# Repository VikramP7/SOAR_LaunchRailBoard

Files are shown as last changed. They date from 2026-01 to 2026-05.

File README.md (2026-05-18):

*<div align="right"> Vikram Procter | Sept 13, 2025 </div>*

# SOAR - Launch Rail Board Specs

## Purpose Overview
- Use AFEs to convert analog sensor data to digital
- Sensors include load cells, thermocouples and anemometers
- Interface with Fill Systems Board (FSB) in Rocket Control Unit (RCU) to provide digital sensor data using UART over Serial RS485
- This board exists on the Launch Rail and is in IP rated box
- The board should also store sensor data to flash memory
- Replacing the Signal Observations Board (SOB) from Ouroboros

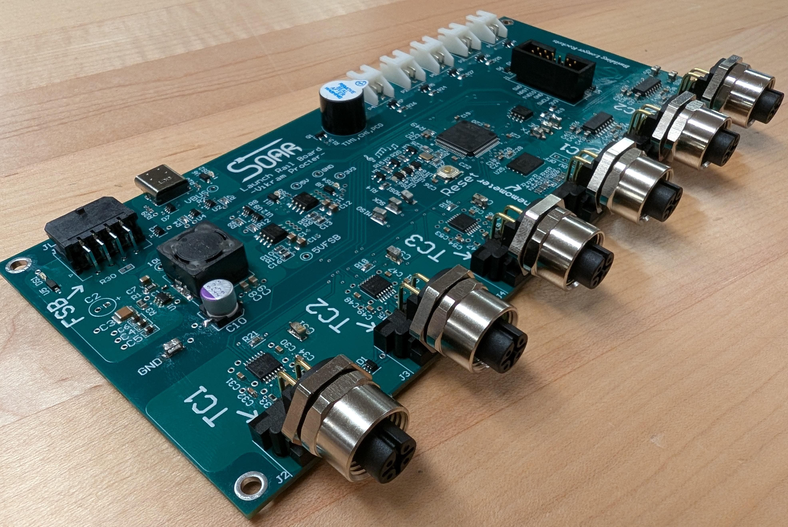
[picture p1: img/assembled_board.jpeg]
Image of Assembled Board


## TODO for V2
- Only use 0603 (remove that stupid 0402 R8)
- Fix same part mismatches (eg. CGA3E2X7R1E104K080AA 0.1uF 0603 and 06035C104KAT2A 100nF 0603)

## Design Review
- [Review Google Doc](https://docs.google.com/document/d/1Cs_T_aiDTq1XPzXbdogT7vXFGTcwQEdisFsmFb62IeU/edit?usp=sharing)

## FSB Connection
### Data Transfer
-   Run simplexed UART over RS-485 twisted pairs
-   Using [Digital to RS485 serial converter](https://www.digikey.ca/en/products/detail/texas-instruments/SN65HVD72D/3283549)

### Power Supply
-   FSB provides 48V

### Connector Choice
-   Board to Wire Molex header [0430450800](https://www.digikey.ca/en/products/detail/molex/0430450800/252529)
-   Board to side panel edge cable assembly [2147561082](https://www.molex.com/en-us/products/part-detail/2147561082), [digikey](https://www.digikey.ca/en/products/detail/molex/2147561082/12180697?s=N4IgTCBcDa4IwBYDsBWAbHADADggXQF8g)
Molex FSB Wiring Standard

-   These are pin numbers based on schematic  

-   Maybe panel Edge connector: M12, 8 position circular connector [54-00184](https://www.digikey.ca/en/products/detail/tensility-international-corp/54-00184/13548494)
-   panel exterior cable 5m Cable [M12A08MR-12AMR-SD005](https://www.digikey.ca/en/products/detail/amphenol-ltw/M12A08MR-12AMR-SD005/21315761)

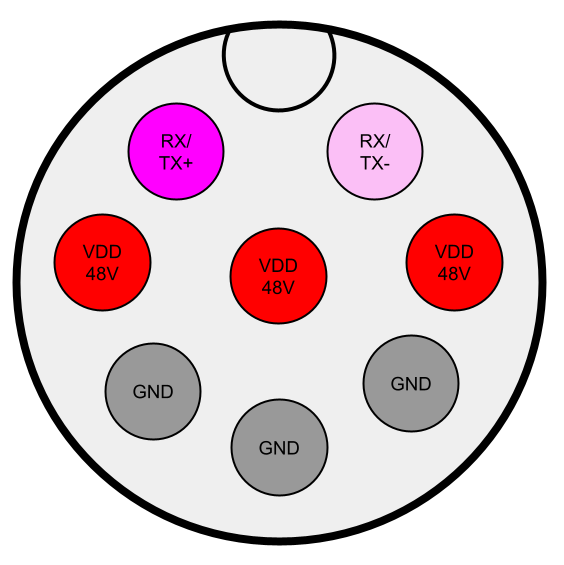
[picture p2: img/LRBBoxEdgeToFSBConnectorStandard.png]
Box Edge LRB to FSB Connector Standard


### RS485 to Digital IC
-   Two [SN65HVD72D](https://www.digikey.ca/en/products/detail/texas-instruments/SN65HVD72D/3283549) ICs will be used to allow for full duplex
-   Each will be used for only Rx or Tx
-   The Tx SN65HVD72D has the DE and RE bar pins held high for driver enable
-   The Rx SN65HVD72D has the DE and RE bar pins held high for receiver enable
-   The connector wires for RS485 will not be connected to ESD protection devices as the SN65HVD72D has built in esd protection

## Power Regulation
-   48V input power stepped down to 10V using Buck converter
-   Power indicator LEDs use [AL5809-20S1-7](https://www.digikey.ca/en/products/detail/diodes-incorporated/AL5809-20S1-7/5030204) for current limiting
### Buck Converter [LMR51625XDDCR](https://www.digikey.ca/en/products/detail/texas-instruments/LMR51625XDDCR/25991371)
- Configuration provided by [Webench SVG](https://webench.ti.com/power-designer/switching-regulator/select) and Ultium Design
- Vout=10V, f=400kHz, Voutpk=18mV, Iout=2A 
- For 10V: $\frac{R_{FBT}}{R_{FBB}}=\frac{V_{out}-0.8}{0.8}=11.5$,
- $R_{FBT}=100k\Omega$ $R_{FBB}=8.66k\Omega$
Buck LMR51625XDDCR Schematic
### LDO Regulator [MIC5209YM](https://www.digikey.ca/en/products/detail/microchip-technology/MIC5209YM/771747)
- For output voltage $V_{out}=1.242V\times(1+\frac{R2}{R1})$ where $R2<470k\Omega$
- For 5V: $\frac{R2}{R1}=3.0257=\frac{453\Omega}{150\Omega}=\frac{47.5k}{15.8k}$
- For 3V3: $\frac{R2}{R1}=1.657=\frac{750\Omega}{453\Omega}=\frac{75k\Omega}{45.3k\Omega}$
- Two caps on output is for ultra low noise, one is optional along with 470pF
### Power Supply Priority
- Allow switching between 5V from USB, programming header, and FSB power, this prioritizes FSB power and ignore usb if usb is plugged in while FSB is providing power. But allow USB to power when FSB is not providing power. The programming header supply has lowest priority and will only be used if no other power sources are connected. 
- ORing of sources is achieved using [LM66100DCKR](https://www.digikey.ca/en/products/detail/texas-instruments/LM66100DCKR/10273183) chip
- This chip also does reverse polarity protection
- Each nCE has a very weak pull down to ensure that the CE is not just floating when other power supplies are not connected.
- This weak pull down does mean that when all power supplies are connected 5V is connected to ground through the 220k. Also if all power supplies are connected 5V are occasionally connected to eachother through a 10k.

*<div align="center">**Power selection truth table:**</div>*
| FSB 5V | USB 5V | PRGM 5V | FSB_nCE | USB_nCE | PRGM_nCE |
|:---:|:---:|:---:|:---:|:---:|:---:|
| 0|0|0  | 0w|0w|0w|
| 0|0|1  | 0 | 1|0w|
| 0|1|0  | 1 |0st|1|
| 0|1|1  | 1 |0st|1|
| 1|0|0  | 0 |1|1fsb|
| 1|0|1  | 0 |1|1fsb|
| 1|1|0  | 0 |1|1fsb|
| 1|1|1  | 0 |1|1fsb|

## Programming Header
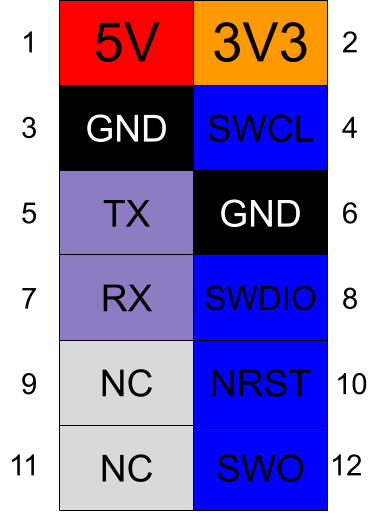
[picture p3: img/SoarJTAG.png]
JTAG
Use 12 pin keyed 2.54mm molex connector [0702461201](https://www.digikey.ca/en/products/detail/molex/0702461201/760167) for Serial Wire Debug Programming protocol 
-   Should be compatible with connector bellow or just free wires
-   Keyed Connector [0022552122](https://www.digikey.ca/en/products/detail/molex/0022552122/313630?s=N4IgTCBcDa5grPMBGMEC6BfIA) and crimps [0016020069](https://www.digikey.ca/en/products/detail/molex/0016020069/1656191?s=N4IgTCBcDaIIwDYAMYlIQThAXQL5A) 24-30 AWG wire gauge
-   Include reset button
-   3V3 is purposefully not connected to 3V3 on board.
-   The STLink connector side uses [0901420010](https://www.digikey.ca/en/products/detail/molex/0901420010/760752) with crimps [0016020069](https://www.digikey.ca/en/products/detail/molex/0016020069/1656191?s=N4IgTCBcDaIIwDYAMYlIQThAXQL5A) (same as the board side so should work)

## Sensors
### What Sensors:
- 1x [Anemometer](): Analog input, connected to MCU ADC.
    - [Adafruit](https://www.adafruit.com/product/1733?srsltid=AfmBOor_Ywvu-j-peoAsiU7YbtJCmZtmGhgEJ9A_gKxrkaFAT5jR3P_o): $44.95 three wire interface (pwr, gnd, signal)
    - [AliExpress](https://www.aliexpress.com/item/1005009826264755.html): $14.08 RS-485 differential pair, I think
    - [Amazon](https://www.amazon.ca/Environment-Anemometer-Greenhouses-Environmental-Stations-ect/dp/B0867KJBCZ/): $46.89 Very similar to ali express, or 4 wire interface. 
- 3x [Thermocouples](): Using [AFE](https://www.digikey.ca/en/products/detail/analog-devices-inc-maxim-integrated/MAX31856MUD/5050138) with SPI output 
- 2x [Load Cells](): Using [AFE](https://www.digikey.ca/en/products/detail/nuvoton-technology-corporation/NAU7802SGI/2769782) with I<sup>2</sup>C output

### Sensor Connectors:
-   M12 screw, 5 position circular board to wire connector [54-00247](https://www.tensility.com/products/54-00247), [digikey](https://www.digikey.ca/en/products/detail/tensility-international-corp/54-00247/13548445)
-   Wire assembly [50-00960](https://www.tensility.com/products/50-00960), [digikey](https://www.digikey.ca/en/products/detail/tensility-international-corp/50-00960/13548425)
LRB FSB connection standard
-   VDD (Pin 1): Provided to only the Load Cell (LC)
-   TC+/LC+ (Pin 2/4): Positive analog signal
-   AN- (Pin 5): Negative Analog signal
-   GND (Pin 3): Ground 

### Data Rate
-	Assume all sensor data is 16bit resolution each + bonus 32bit

## File System Over USB
-   USB C interface with STM to allow the LRB to show up as a mass storage device to offload data
-   If LRB can be powered over USB then that would be good for data offload to not require FSB
-   Using USB FS (no external phys required)
-   Using USB C and USB ab for compatibility, USB C will be conversion of old USB ab

## Flash Memory
-   Targeting 16 bit resolution and 1kHz sampling rate
-   `16bit * 4sensors + 32bonus bits = 96bit/sample `
-   `(96bit/sample)*(1000samples/s)*(1byte/8bits) = 12kB/s`
-   If data measuring is needed for 6 hours, total storage needs to be greater than **259.2MB**, **2073.6Mbit**
-   Using one [(*W25N04KVZEIR*)](https://www.digikey.ca/en/products/detail/winbond-electronics/W25N04KVZEIR/15182086) 4Gbit flash chip
-   Chip uses QuadSPI

## Buzzer
-   Using Same Sky [CMI-1210-5-95T](https://www.digikey.ca/en/products/detail/same-sky-formerly-cui-devices/CMI-1210-5-95T/15904111)
-   Connected to PWM PC0: TIM1, PWM Gen CH1 using NPN [MMBT3904-TP](https://www.digikey.ca/en/products/detail/micro-commercial-co/MMBT3904-TP/717395)

## Microcontroller Specs
### Data Sheet
-   [STM32G491ME
](https://www.st.com/resource/en/datasheet/stm32g491cc.pdf) data sheet

### System and Programming
-   BOOT0 pin is pulled down to GND through 10k, pad are there to change in future
-   Serial Wire Debug Programming protocol is used with NRST pin connected to reset button

### Power Supply
-   Supply voltage 1.71 V to 3.6 V
-   Each VDD pin should have a 100nF decoupling cap
-   VDD should also have one 4.7uF decoupling cap
-   VDDA should have 10nF and 1uF decoupling cap (Pg. 70)
-   VREF+ should be connected to VDDA if VDDA > 2V (Pg. 22)
-   VREF+ should have 100nF and 1uF decoupling cap (Pg. 70)

### Oscillator
-   Using the 32MHz and 9pF oscillator [ABM8-32.000MHZ-B2-T](https://www.digikey.ca/en/products/detail/abracon-llc/ABM8-32-000MHZ-B2-T/2001197)
-   With an Assumed PCB and connector capacitance of Cs=4-6pF
-   Using the equation $C_{L1}=C_{L2}=2*(C_L-C_S)$ ref. [design guide](https://www.st.com/resource/en/application_note/an2867-guidelines-for-oscillator-design-on-stm8afals-and-stm32-mcusmpus-stmicroelectronics.pdf) pg. 12
-   $C_{L1}=C_{L2}=2*(18pF-6pF)=24pF$
-    The STM32G491ME microcontroller specifies that $G_{m,crit}=1.5mA/V$
-   The $G_{m,crit}$ of the oscillator is given by the equation $G_{m,crit}=4*ESR*(2\pi F)^2*(C_0+C_L)^2$
-   This oscillator has a $G_{m,crit}= 4*40\Omega*(2\pi (32MHz))^2*(3pF+18pF)^2$
-   $G_{m,crit}=2.852451478mA/V$
-   For calculating the external resistor ref. [design guide](https://www.st.com/resource/en/application_note/an2867-guidelines-for-oscillator-design-on-stm8afals-and-stm32-mcusmpus-stmicroelectronics.pdf) pg. 16 
-   Given by $R_{ext} = 1/(2\pi F C_{L2})=190to220\Omega$ depending on $C_s$
-   The page cautions that $G_m>>G_{m,crit}=4*(ESR+R_{ext})*(2\pi F)^2*(C_0+C_L)^2=17.11470887mA/V$
-   This oscillator meets the requirements with $C_{L1}=C_{L2}=2*(18pF-7pF)=22pF$ and $R_{ext} = 221\Omega$

### Connectivity
-   Flash Memory interfaces using Quad SPI1
-   Thermo Couples connect to SPI1 and use 9 GPIOs for TC1, TC2, TC3 respectively:
    - CS: PD2, PB6, PD9
    - nDRDY: PB4, PB7, PD8
    - nFault: PD1, PB5, PD10
-   2 Load Cells connect to I2C3
-   Anemometer can use ADC1 in1 in differential mode (PA0:AN+, PA1:AN-)
-   FSB USART connection uses USART 3 with hardware flow control for RS485
-   Debug communication uses USART2 
-   File system utilizes the only USB FS on the chip

### Debug
-   Debug External LEDs (PA15, PC10, PC11, PC12, PD0)
-   Debug on board LEDs (PC13, PC14, PC15). These pins convienently specify not to use them to power LEDs. So using same thing as the external with low side NMOS switch.
-   Test points on all power rails (stupid orange ones ) 
-   Clips [RCWCTE](https://www.digikey.ca/en/products/detail/koa-speer-electronics-inc/RCWCTE/11476558) on I2C lines, SPI lines (including CS), Debug UART, and FSB UART (with DE) 

### External LEDs
-   Board side connector [S2B-XH-A](https://www.digikey.ca/en/products/detail/jst-sales-america-inc/S2B-XH-A/1651055)
-   Connector Housing [XHP-2](https://www.digikey.ca/en/products/detail/jst-sales-america-inc/XHP-2/555485)
-   Housing Crimp [SXH-001T-P0.6N](https://www.digikey.ca/en/products/detail/jst-sales-america-inc/SXH-001T-P0-6N/7041446)
-   Box edge waterproof leds from [AliExpress](https://www.aliexpress.com/item/1005008982081981.html)

## Enclosure
-   Water proof box [AliExpress 220X170X110mm](https://www.aliexpress.com/item/1005007437283895.html)
-   Drill holes in this box for connectors and LEDs
-   3D printed pcb in box mount (all in cm)
    - Height = 1.75+16.75+1.75
    - Holes vertically spaced 16.75 center to center
    - Holes horizontally spaced 2.00
    - Width = 9.00
    - Depth = 0.90

## Glossary
- FSB: Fill Systems Board
- AFE: Analog Front End
- USB FS: Universal Serial Bus Full Speed
- LC: Load Cell
- TC: Thermo couple
- CS: chip select

## Completed TODO
- ~~Find FSB connector~~
- ~~Define FSB connector wiring standard~~
- ~~Connector ESD Protection~~
- ~~Figure out Reset Button, and buzzer~~
- ~~I2C pull ups please~~
- ~~Figure out how to do USB vs FSB power supply switching (ORing LM66100)~~
- ~~Add indicator LEDs (Power, USB power, MCU debug)~~
- ~~Mounting holes~~
- ~~Find external LED indicators connector wire assembly~~
- ~~Fix inductor to have larger current max~~
- ~~Add lots of silkscreen~~
    - ~~Sensor types~~
    - ~~label R31 as a jumper to ground~~
    - ~~Your name (maybe in copper)~~
    - ~~Description~~
    - ~~JLCJCLJLC add to silk screen for tracking number~~
    - ~~Shorten Thermo couple name~~
    - ~~Add rocket name~~
- ~~Fix 5V Power source ORing for programming header~~
- ~~Fix MCU debug LEDs to use fet~~
- ~~Swap USB-C to through hole footprint~~
- ~~Source box edge LED indicators~~
- ~~Design water proof box~~
- ~~Assembly~~

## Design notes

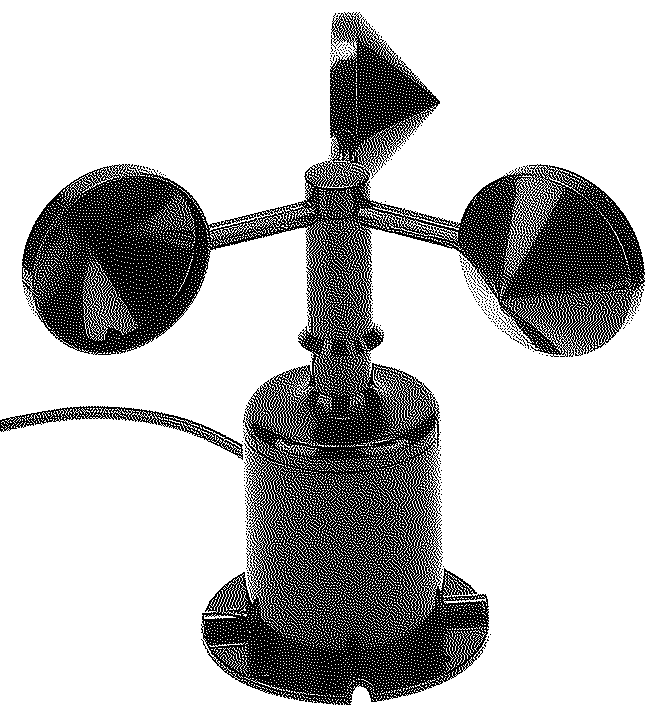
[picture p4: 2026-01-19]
img/anemomBW_Dithered.png

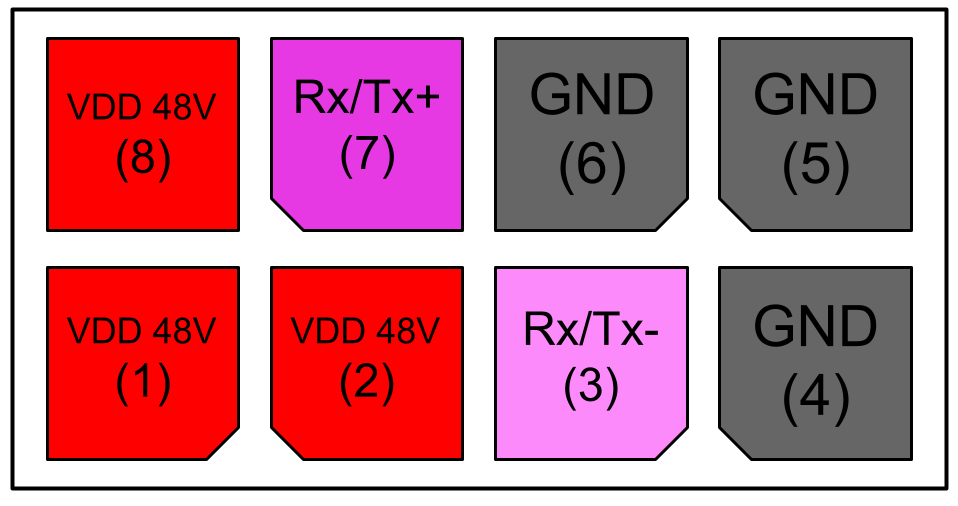
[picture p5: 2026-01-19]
img/LRB_FSB_InternalConnectorStandard.png

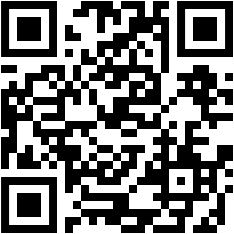
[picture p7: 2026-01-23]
img/gitlinkqr_sm.jpg

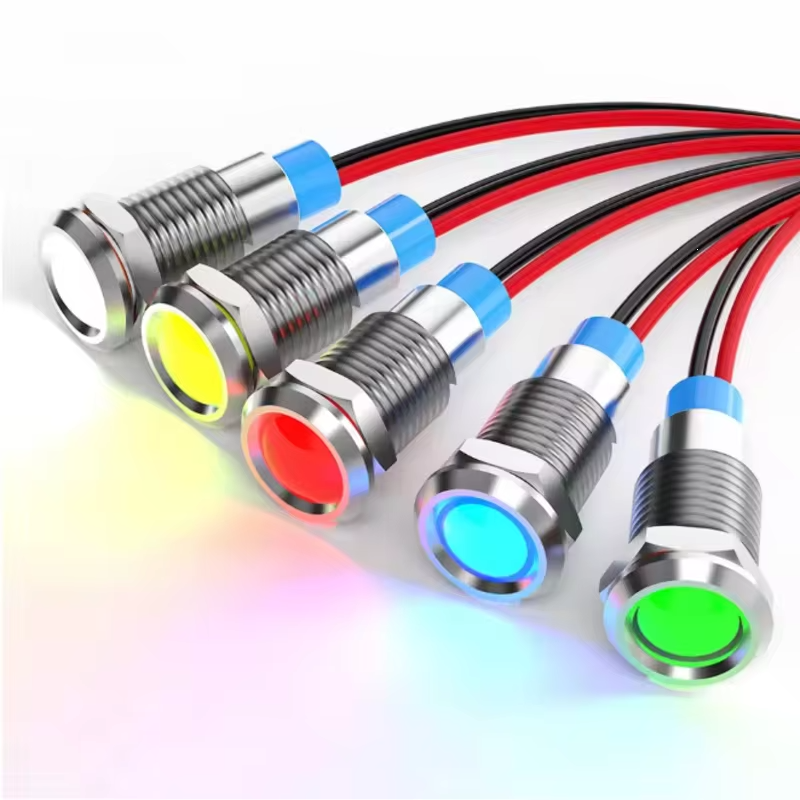
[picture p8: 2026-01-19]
img/extLEDs.png

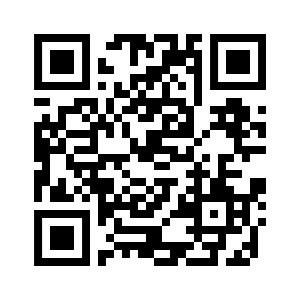
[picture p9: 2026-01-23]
img/gitlinkqr.png

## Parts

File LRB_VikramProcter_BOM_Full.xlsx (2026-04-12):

Line # | Name | Description | Designator | Revision ID | Revision Status | Quantity | Manufacturer 1 | Manufacturer Part Number 1 | Manufacturer Lifecycle 1 | Supplier 1 | Supplier Part Number 1 | Supplier Unit Price 1 | Supplier Subtotal 1
 | Capacitor 100nF +/-20% 50V 0402 | Chip Capacitor, 100nF +/-20%, 50V, 0402, Thickness 0.6 mm | C1 |  |  | 1 | Yageo Group | CC0402KRX5R9BB104 | Volume Production | DigiKey | 311-3342-1-ND | 0.08 | 0.08
 | CAP ELC 2.2uF 50V 20% | ECA1HM2R2 Aluminum Electrolytic Capacitor, 2.2 uF, +/- 20%, 50 V, -40 to 85 degC, 2-Pin THD, RoHS, Bulk | C2 |  |  | 1 | Panasonic | ECA-1HM2R2 | Volume Production | RS (Formerly Allied Electronics) | ECA-1HM2R2 | 0.02 | 0.02
 | CAP CER 100nF 100V 10% 1210 | C1210C104K1RACAUTO - Cap Ceramic 0.1uF 100V X7R 10% Pad SMD 1210 125C Automotive T/R | C3 |  |  | 1 | KEMET | C1210C104K1RACAUTO | Volume Production | DigiKey | 399-7043-1-ND | 0.36 | 0.36
 | CAP CER 1uF 50V X5R 0603 | CL10A105KB8NNNC - Ceramic Capacitor, Multilayer, Ceramic, 50V, 10% +Tol, 10% -Tol, X5R, 15% TC, 1uF, Surface Mount, 0603 | C4, C5, C6 |  |  | 3 | Samsung Electro-Mechanics | CL10A105KB8NNNC | Volume Production | DigiKey | 1276-1860-1-ND | 0.11 | 0.33
 | Capacitor 10µF +/-20% 25V 0805 | Chip Capacitor, 10µF +/-20%, 25V, 0805, Thickness 1.45 mm | C7, C8, C9 |  |  | 3 | Murata | GRM21BR61E106KA73L | Volume Production | DigiKey | 490-5523-1-ND | 0.17 | 0.51
 | CAP ELC 47uF 25V 20% 2626 | 25SVPF47M - Aluminum Electrolytic Capacitor, Polarized, -Aluminum (wet), 25V, 20% +Tol, 20% -Tol, 47uF, Surface Mount, 2626 | C10 |  |  | 1 | Panasonic | 25SVPF47M | Volume Production | Mouser | 667-25SVPF47M | 1.34 | 1.34
 | Capacitor 1 uF +/- 10% 25 V 0805 | Chip Capacitor, 1 uF, +/-10%, 25 V, 0805 (2012 Metric) | C11, C12, C14, C15 |  |  | 4 | Yageo Group | CC0805KKX7R8BB105 | Volume Production | Farnell | 1458903 | 0.09089 | 0.45446
 | CAP 470pF FILM 16V 0603 | ECHU1C471GX5 Film Capacitor, Plastic, 16V, 2% +Tol, 2% -Tol, 0.00047uF, Surface Mount, 0603, ECHU1C471GX5 | C13, C16 |  |  | 2 | Panasonic | ECHU1C471GX5 | Volume Production | Farnell | 2326062 | 0.27967 | 2.8
 | CAP CER 4.7µF +/-20% 10V 0603 | CC0603MRX5R6BB475 Chip Capacitor, 4.7µF +/-20%, 10V, 0603, Thickness 1 mm | C17 |  |  | 1 | Yageo Group | CC0603MRX5R6BB475 | Volume Production | DigiKey | 311-1820-1-ND | 0.16 | 0.16
 | Capacitor 1µF +/-20% 10V 0402 | Chip Capacitor, 1µF +/-20%, 10V, 0402, Thickness 0.6 mm | C18, C29 |  |  | 2 | KYOCERA AVX | 0402ZD105KAT2A | Volume Production | Newark | 0402ZD105KAT2A | 0.011 | 0.022
 | CAP CER 0.1UF 25V 0603 | CGA3E2X7R1E104K080AA CAP CER 0.1UF 25V X7R 0603 | C19, C20, C21, C22, C23, C24, C26, C30, C31, C33, C47, C48, C50, C52, C53, C55 |  |  | 16 | TDK | CGA3E2X7R1E104K080AA | Volume Production | Mouser | 810-CGA3E2X7R1E104K | 0.026 | 0.416
 | CAP CER 22pF 5% 50V C0G 0603 | GRM1885C1H220JA01D - 22 pF ±5% 50V Ceramic Capacitor C0G, NP0 0603 (1608 Metric) | C25, C27 |  |  | 2 | MURATAPS POWER | GRM1885C1H220JA01D
 | CAP CER 10nF 50V 10% 0603 | C0603C103K5RACTU - Multilayer Ceramic Capacitors Mlcc - Smd/Smt 50V 0.01Uf X7R 0603 10% | C28 |  |  | 1 | KEMET | C0603C103K5RACTU | Volume Production | DigiKey | 399-C0603C103K5RACTUDKR-ND | 0.08 | 0.08
 | CGA3E2X7R1H103K080AA | CAP CER 10000PF 50V X7R 0603 | C32, C34, C49, C51, C54, C56 |  |  | 6 | TDK | CGA3E2X7R1H103K080AA | Volume Production | Mouser | 810-CGA3E2X7R1H103K | 0.025 | 0.25
 | Capacitor 1 uF +/- 10% 50 V 0805 | Chip Capacitor, 1 uF, +/- 10%, 50 V, 0805 (2012 Metric) | C35, C37, C41, C43 |  |  | 4 | TDK | C2012X7R1H105K125AB | Volume Production | Mouser | 810-C2012X7R1H105K | 0.26 | 1.04
 | Capacitor 100 nF +/-10% 50 V 0603 | Chip Capacitor, 100 nF, +/- 10%, 50 V, 0603 (1608 Metric) | C36, C38, C39, C42, C44, C45 |  |  | 6 | KYOCERA AVX | 06035C104KAT2A | Volume Production | RS (Formerly Allied Electronics) | 06035C104KAT2A | 0.02 | 0.12
 | CAP CER 330pF 50V 1% 0603 | KGM15ACG1H331FT - Cap Ceramic 330pF 50V C0G 1% Pad SMD 0603 125C T/R | C40, C46 |  |  | 2 | KYOCERA AVX | KGM15ACG1H331FT | Volume Production | DigiKey | 478-KGM15ACG1H331FTCT-ND | 0.36 | 0.72
 | USB4085-GF-A | USB Connector, 16 Contact(s), Female, Right Angle, Solder Terminal, Locking, Receptacle | CN1 |  |  | 1 | Global Connector Technology | USB4085-GF-A | Volume Production | DigiKey | 2073-USB4085-GF-ACT-ND | 0.88 | 0.88
 | TP Clip 1206 RCWCTE | PC TEST POINT 1206 footprint RCWCTE | CS1, CS2, CS3, D_Rx, D_Tx, DE, GND, MISO, MOSI, Rx, SCK, SCL, SDA, Tx |  |  | 14 |  | RCWCTE
 | DI TVS 6V | ESD Suppressors / TVS Diodes 4 Ch TVS Diode Array 3.3V 6.0A 200mW | D1, D2, D3, D4, D5, D6, D7 |  |  | 7 | Diodes Inc. | D1213A-04S-7 | Volume Production | DigiKey | D1213A-04S-7DICT-ND | 0.23 | 2.3
 | LTST-C190KRKT | LED Uni-Color Red, 62.5 mW, 25 mA, -30 to 85 degC, 2-Pin SMD, RoHS, Tape and Reel | DS1, DS2, DS3, DS4, DS5, DS6, DS7 |  |  | 7 | Lite-On | LTST-C190KRKT | Volume Production | DigiKey | 160-1436-6-ND | 0.098 | 0.98
 | HSMG-C190 | LED Uni-Color Green, 52 mW, 20 mA, -40 to 85 degC, 2-Pin SMD, RoHS, Tape and Reel | DS8 |  |  | 1 | Agilent | HSMG-C190 | Volume Production | Mouser | 630-HSMG-C190 | 0.28 | 0.28
 | CON 0702461201 | Conn Shrouded Header (4 Sides) HDR 12 POS 2.54mm Solder ST Top Entry Thru-Hole C-Grid® Tray | J1 |  |  | 1 | Molex | 70246-1201 | Volume Production | Newark | 70246-1201 | 1.45 | 1.45
 | CON 54-00247 | Circular Connector, 5 Contact(s), Brass, Female, Solder Terminal, Socket | J2, J3, J4, J7, J8, J9 |  |  | 6 | Tensility | 54-00247
 | CON 0430450800 | 0430450800 Connector Header Through Hole, Right Angle 8 position 0.118" (3.00mm) | J5 |  |  | 1 |  | 430450800
 | 2.54mm | TS-104-G-AA | J6 |  |  | 1 | Samtec | TS-104-G-AA | Volume Production | Avnet | TS-104-G-AA | 1.37 | 1.37
 | IND WIR 22uH 3.5A 20% | SRR1208-220ML Inductor Power Shielded Wirewound 22uH 20% 1KHz 23Q-Factor Ferrite 3.5A 0.043Ohm DCR T/R SRR1208-220ML | L1 |  |  | 1 | Bourns | SRR1208-220ML | Volume Production | DigiKey | 118-SRR1208-220MLCT-ND | 0.9 | 0.9
 | BUZZ MAG 5V 12MM TH | CMI-1210-5-95T 12 mm, 5 Vdc, 98 dB, Through Hole, Magnetic Audio Indicator Buzzer CMI-1210-5-95T | LS1 |  |  | 1 | Same Sky | CMI-1210-5-95T | Volume Production | DigiKey | 2223-CMI-1210-5-95T-ND | 1.49 | 1.49
 | MOS NMOS 30V 5.6A SOT-23 | PJA3404_R1_00001 - Power Field-Effect Transistor, 5.6A I(D), 30V, 0.03ohm, 1-Element, N-Channel, Silicon, Metal-oxide Semiconductor FET | M1, M2, M3, M4, M5, M6, M7, M8 |  |  | 8 | Panjit | PJA3404_R1_00001 | Volume Production | Mouser | 241-PJA3404_R1_00001 | 0.17 | 1.7
 | S2B-XH-A(LF)(SN) | Male Header, Pitch 2.5 mm, 1 x 2 Position, Height 6.1 mm, Tail Length 3.4 mm, -25 to 85 degC, RoHS, Bulk | P1, P2, P3, P4, P5 |  |  | 5 | JST | S2B-XH-A(LF)(SN) | Volume Production | Newark | S2B-XH-A (LF)(SN) | 0.082 | 0.41
 | NPN 350mW 40V 200mA | Transistor, Bipolar, Si, NPN, Amplifier, Small Signal, Vceo 40VDC, IC 200MA, Pd 350MW | Q1 |  |  | 1 | MCC | MMBT3904-TP | Volume Production | DigiKey | MMBT3904TPMSDKR-ND | 0.1 | 0.1
 | Resistor 100k +/-1% 0805 125 mW | Chip Resistor, 100 KOhm, +/- 1%, 0.125 W, -55 to 155 degC, 0805 (2012 Metric) | R1 |  |  | 1 | Yageo Group | RC0805FR-07100KL | Volume Production | DigiKey | 311-100KCRDKR-ND | 0.1 | 0.1
 | Resistor 10k +/-1% 0402 100 mW | Chip Resistor, 10 KOhm, +/- 1%, 0.1 W, -55 to 155 degC, 0402 (1005 Metric) | R2, R8 |  |  | 2 | Panasonic | ERJ-2RKF1002X | Volume Production | Mouser | 667-ERJ-2RKF1002X | 0.016 | 0.16
 | RES 8.66K OHM 1% 1/8W 0805 | RMCF0805FT8K66 Res Thick Film 0805 8.66K Ohm 1% 1/8W ±100ppm/°C Molded SMD SMD Paper T/R RMCF0805FT8K66 | R3 |  |  | 1 | Stackpole Electronics | RMCF0805FT8K66 | Volume Production | Arrow Electronics | RMCF0805FT8K66 | 0.0027 | 0.0027
 | RMCF0603FT220K | Res Thick Film 0603 220K Ohm 1% 0.1W(1/10W) ±100ppm/C Pad SMD Automotive T/R | R4, R7, R9, R12 |  |  | 4 | TE Connectivity | CRGCQ0603F220K | Volume Production | Newark | CRGCQ0603F220K | 0.002 | 0.008
 | RES 43.5kR 0.15W 0.1% 0603 | RQ73C1J45K3BTD - Fixed Resistor, Thin Film, 0.15W, 45300ohm, 75V, 0.1% +/-Tol, 10ppm/Cel, Surface Mount, 0603 | R5 |  |  | 1 | TE Connectivity / AMP | 9-2176371-6 | Volume Production | DigiKey | A140887CT-ND | 0.46 | 0.46
 | RES 75k 1% 0.1W 0603 | Fixed Resistor, Metal Glaze/thick Film, 0.1W, 75000ohm, 75V, 1% +/-Tol, 100ppm/Cel, Surface Mount, 0603 RMCF0603FT75K0 | R6 |  |  | 1 | Stackpole Electronics | RMCF0603FT75K0 | Volume Production | Arrow Electronics | RMCF0603FT75K0 | 0.0019 | 0.0038
 | RES 15.8k 1% 0.1W 0603 | Fixed Resistor, Metal Glaze/thick Film, 0.1W, 15800ohm, 75V, 1% +/-Tol, 100ppm/Cel, Surface Mount, 0603 RC0603FR-0715K8L | R10 |  |  | 1 | Yageo Group | RC0603FR-0715K8L | Volume Production | Farnell | 3950923 | 0.00901 | 0.09009
 | RES 47.5k 1% 0.1W 0603 | Fixed Resistor, Metal Glaze/thick Film, 0.1W, 47500ohm, 75V, 1% +/-Tol, 100ppm/Cel, Surface Mount, 0603 ERJ-3EKF4752V | R11 |  |  | 1 | Panasonic | ERJ-3EKF4752V | Volume Production | Mouser | 667-ERJ-3EKF4752V | 0.1 | 0.1
 | ERJ-2GEJ241x | Chip Resistor, 240 Ohm, +/- 5%, 100 mW, -55 to 155 degC, 0402 (1005 Metric), RoHS, Tape and Reel | R13 |  |  | 1 | Panasonic | ERJ-2GEJ241X | Volume Production | Mouser | 667-ERJ-2GEJ241X | 0.12 | 0.12
 | Resistor 10k +/-1% 0805 125 mW | Chip Resistor, 10 KOhm, +/- 1%, 125 mW, -55 to 155 degC, 0805 (2012 Metric) | R14, R15, R20, R23, R24, R25, R26, R27 |  |  | 8 | Yageo Group | RC0805FR-0710KL | Volume Production | DigiKey | 311-10.0KCRDKR-ND | 0.009 | 0.09
 | CRGCQ0603F2K2, 2.2k | Fixed Resistor, Metal Glaze/thick Film, 0.1W, 2200ohm, 75V, 1% +/-Tol, 100ppm/Cel, Surface Mount, 0603 | R16, R18, R21, R49 |  |  | 4 | TE Connectivity | CRGCQ0603F2K2 | Volume Production | Farnell | 2861465 | 0.01681 | 0.16807
 | Resistor 4k7 +/-1% 0805 125 mW | Chip Resistor, 4.7 KOhm, +/- 1%, 0.125 W, -55 to 155 degC, 0805 (2012 Metric) | R17, R19 |  |  | 2 | Vishay | CRCW08054K70FKEA | Volume Production | Newark | CRCW08054K70FKEA | 0.026 | 0.052
 | RES 220R 5% 100mW 0603 | CRGCQ0603J220R - Fixed Resistor, Metal Glaze/thick Film, 0.1W, 220ohm, 75V, 5% +/-Tol, 100ppm/Cel, Surface Mount, 0603 | R22 |  |  | 1 | TE Connectivity | CRGCQ0603J220R | Volume Production | Arrow Electronics | CRGCQ0603J220R | 0.0007 | 0.0007
 | RC0603FR-075K1L | Fixed Resistor, Metal Glaze/thick Film, 0.1W, 5100ohm, 75V, 1% +/-Tol, 100ppm/Cel, Surface Mount, 0603 | R28, R29 |  |  | 2 | Yageo Group | RC0603FR-075K1L | Volume Production | DigiKey | 311-5.10KHRCT-ND | 0.007 | 0.07
 | RT-0R00-F-1/10W-0603 | 0 Ohms Jumper 0.1W, 1/10W Chip Resistor 0603 (1608 Metric) Automotive AEC-Q200 Thick Film | R30, R31, R32 |  |  | 3
 | ERJ-3EKF1000V | Fixed Resistor, Metal Glaze/thick Film, 0.1W, 100ohm, 75V, 1% +/-Tol, 100ppm/Cel, Surface Mount, 0603 | R33, R34, R45, R46, R47, R48 |  |  | 6 | Panasonic | ERJ-3EKF1000V | Volume Production | Mouser | 667-ERJ-3EKF1000V | 0.021 | 0.21
 | RG1608N-470-W-T1 | Fixed Resistor, Metal Film, 0.1W, 47ohm, 75V, 0.05% +/-Tol, 10ppm/Cel, Surface Mount, 0603 | R35, R36, R43, R44 |  |  | 4 | Susumu | RG1608N-470-W-T1 | Obsolete | DigiKey | RG16N47WCT-ND | 0.57 | 2.28
 | RMCF0603FT220K | Res Thick Film 0603 220K Ohm 1% 0.1W(1/10W) ±100ppm/C Pad SMD Automotive T/R | R37, R38, R39, R40, R41, R42 |  |  | 6 | Stackpole Electronics Inc | RMCF0603FT220K
 | BTN 12V 0.05A PTS526SMG15SMTR2 LFS | Switch Tactile N.O. SPST Round Button Gull Wing 0.05A 12VDC 500000Cycles 1.57N SMD T/R PTS526SMG15SMTR2 LFS | SW1 |  |  | 1 | C&K Components | PTS526SMG15SMTR2LFS | Volume Production | Newark | PTS526 SMG15 SMTR2 LFS | 0.059 | 0.059
 | 5003 | Test Point, Orange, Height 4.6 mm, Tail Length 3 mm, 1-Pin THD, RoHS | TP1, TP2, TP3, TP4, TP5, TP6, TP7, TP8 |  |  | 8 | Keystone | 5003 | Volume Production | Farnell | 2301280 | 0.27026 | 2.16
 | IC BUCK LMR51625XDDCR | SIMPLE SWITCHER® synchronous buck converter with 4.3V-to-60V, 2.5A and low quiescent current 6-SOT-23-THIN -40 to 150 | U1 |  |  | 1 | Texas Instruments | LMR51625XDDCR | Volume Production | DigiKey | 296-LMR51625XDDCRCT-ND | 2.03 | 2.03
 | LM66100 | 1.5-V to 5.5-V, 1.5-A, 0.5-µA IQ ideal diode with integrated FET 6-SC70 -40 to 105 | U2, U4, U9, U12 |  |  | 4 | Texas Instruments | LM66100DCKT | Volume Production | Mouser | 595-LM66100DCKT | 0.85 | 3.4
 | MIC5209YM-TR | IC REG LIN POS ADJ 500MA 8SOIC | U3, U10 |  |  | 2 | Microchip Technology | MIC5209YM-TR
 | AL5809-20S1-7 | Led Driver, Cc/Linear, -40 To 125Deg C Rohs Compliant: Yes | U5, U6, U7, U8, U11, U14, U15, U16, U17, U18, U19, U20, U21 |  |  | 13 | Diodes Inc. | AL5809-20S1-7 | Volume Production | DigiKey | AL5809-20S1-7DICT-ND | 0.279 | 3.63
 | STM32G491ME | MCU 32-Bit ARM Cortex-M4 RISC 512kByte Flash 1.71V to 3.6V 80-Pin LQFP Tray | U13 |  |  | 1 | STMicroelectronics | STM32G491MET6 | Volume Production | Farnell | 3648860 | 8.01 | 8.01
 | SN65HVD72D RS485 | Line Transceiver, 1 Func, 1 Driver, 1 Rcvr, PDSO8 | U22 |  |  | 1 | Texas Instruments | SN65HVD72D | Volume Production | Mouser | 595-SN65HVD72D | 3.38 | 3.38
 | MAX31856MUD+ | Analog Circuit, 1 Func, PDSO14 | U23, U27, U28 |  |  | 3 | Maxim | MAX31856MUD+
 | NAU7802SGI | ADC, Delta-Sigma, 24-Bit, 1 Func, 2 Channel, Serial Access, PDSO16 | U24, U26 |  |  | 2 | Nuvoton | NAU7802SGI | Volume Production | DigiKey | NAU7802SGI-ND | 1.62 | 3.24
 | W25N04KVZEIR 4Gb 3V Nand | 4G-BIT Serial Nand Flash, 3V | U25 |  |  | 1 | Winbond | W25N04KVZEIR | Volume Production | DigiKey | 256-W25N04KVZEIR-TRAY-ND | 10.07 | 10.07
 | CRY 32MHZ 18PF SMD | Crystal 32MHz ±20ppm (Tol) ±50ppm (Stability) 18pF FUND 40Ohm 4-Pin Ultra Mini-CSMD T/R | Y1 |  |  | 1 | Abracon | ABM8-32.000MHZ-B2-T | Volume Production | DigiKey | 535-9830-1-ND | 0.43 | 0.43

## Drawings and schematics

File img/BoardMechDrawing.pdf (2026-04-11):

6

5

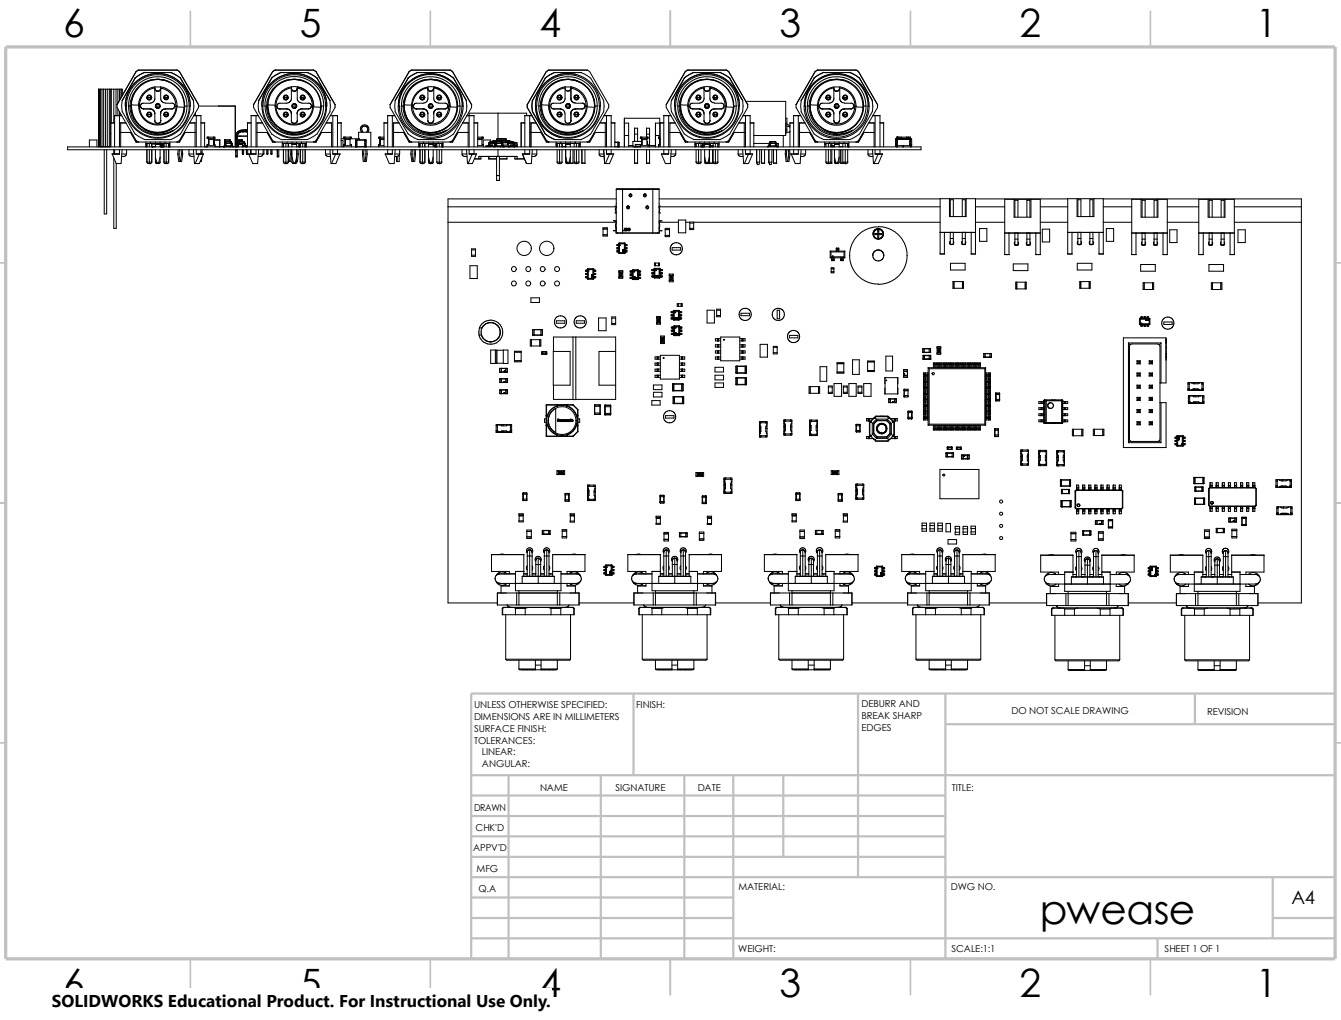
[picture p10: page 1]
WEIGHT:; SCALE:1:1; SHEET 1 OF 1; DO NOT SCALE DRAWING; REVISION; FINISH:; EDGES; DEBURR AND BREAK SHARP

UNLESS OTHERWISE SPECIFIED:
DIMENSIONS ARE IN MILLIMETERS
SURFACE FINISH:
TOLERANCES:
LINEAR:
ANGULAR:

NAME | SIGNATURE | DATE | | | | TITLE:

DRAWN
CHK'D
APPV'D

MFG
Q.A | | | | MATERIAL: | DWG NO. pwease | A4

SOLIDWORKS Educational Product. For Instructional Use Only.

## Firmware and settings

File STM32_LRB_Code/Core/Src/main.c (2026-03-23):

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
/* Includes ------------------------------------------------------------------*/
#include "main.h"
#include "adc.h"
#include "i2c.h"
#include "quadspi.h"
#include "spi.h"
#include "tim.h"
#include "usart.h"
#include "usb.h"
#include "gpio.h"


void SystemClock_Config(void);
/**
  * @brief  The application entry point.
  * @retval int
  */
int main(void)
{

  /* MCU Configuration--------------------------------------------------------*/

  /* Reset of all peripherals, Initializes the Flash interface and the Systick. */
  HAL_Init();

  /* Configure the system clock */
  SystemClock_Config();

  /* Initialize all configured peripherals */
  MX_GPIO_Init();
  MX_QUADSPI1_Init();
  MX_SPI1_Init();
  MX_USB_PCD_Init();
  MX_USART2_UART_Init();
  MX_USART3_UART_Init();
  MX_ADC1_Init();
  MX_I2C3_Init();
  MX_TIM1_Init();
  /* Infinite loop */
  /* USER CODE BEGIN WHILE */
  HAL_GPIO_WritePin(Ext_ind_led1_GPIO_Port, Ext_ind_led1_Pin, GPIO_PIN_SET);
  HAL_GPIO_WritePin(Ext_ind_led2_GPIO_Port, Ext_ind_led2_Pin, GPIO_PIN_SET);
  HAL_GPIO_WritePin(Ext_ind_led3_GPIO_Port, Ext_ind_led3_Pin, GPIO_PIN_SET);
  HAL_GPIO_WritePin(Ext_ind_led4_GPIO_Port, Ext_ind_led4_Pin, GPIO_PIN_SET);
  HAL_GPIO_WritePin(Ext_ind_led5_GPIO_Port, Ext_ind_led5_Pin, GPIO_PIN_SET);

  HAL_GPIO_WritePin(Debug_led1_GPIO_Port, Debug_led1_Pin, GPIO_PIN_SET);
  while (1)
  {
    /* USER CODE END WHILE */

    /* USER CODE BEGIN 3 */
  }
  /* USER CODE END 3 */
}

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


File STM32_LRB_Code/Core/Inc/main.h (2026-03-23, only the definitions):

#define Debug_led1_Pin GPIO_PIN_13
#define Debug_led1_GPIO_Port GPIOC
#define Debug_led2_Pin GPIO_PIN_14
#define Debug_led2_GPIO_Port GPIOC
#define Debug_led3_Pin GPIO_PIN_15
#define Debug_led3_GPIO_Port GPIOC
#define RESET_Pin GPIO_PIN_10
#define RESET_GPIO_Port GPIOG
#define USART3_TX_FSB_Pin GPIO_PIN_10
#define USART3_TX_FSB_GPIO_Port GPIOB
#define USART3_RX_FSB_Pin GPIO_PIN_11
#define USART3_RX_FSB_GPIO_Port GPIOB
#define LC2_DRDY_Pin GPIO_PIN_12
#define LC2_DRDY_GPIO_Port GPIOB
#define LC1_DRDY_Pin GPIO_PIN_13
#define LC1_DRDY_GPIO_Port GPIOB
#define USART3_DE_FSB_Pin GPIO_PIN_14
#define USART3_DE_FSB_GPIO_Port GPIOB
#define TC3_nReady_Pin GPIO_PIN_8
#define TC3_nReady_GPIO_Port GPIOD
#define TC3_cs_Pin GPIO_PIN_9
#define TC3_cs_GPIO_Port GPIOD
#define TC3_nFAULT_Pin GPIO_PIN_10
#define TC3_nFAULT_GPIO_Port GPIOD
#define Ext_ind_led1_Pin GPIO_PIN_15
#define Ext_ind_led1_GPIO_Port GPIOA
#define Ext_ind_led2_Pin GPIO_PIN_10
#define Ext_ind_led2_GPIO_Port GPIOC
#define Ext_ind_led3_Pin GPIO_PIN_11
#define Ext_ind_led3_GPIO_Port GPIOC
#define Ext_ind_led4_Pin GPIO_PIN_12
#define Ext_ind_led4_GPIO_Port GPIOC
#define Ext_ind_led5_Pin GPIO_PIN_0
#define Ext_ind_led5_GPIO_Port GPIOD
#define TC1_nFault_Pin GPIO_PIN_1
#define TC1_nFault_GPIO_Port GPIOD
#define TC1_cs_Pin GPIO_PIN_2
#define TC1_cs_GPIO_Port GPIOD
#define TC1_nReady_Pin GPIO_PIN_4
#define TC1_nReady_GPIO_Port GPIOB
#define TC2_nFault_Pin GPIO_PIN_5
#define TC2_nFault_GPIO_Port GPIOB
#define TC2_cs_Pin GPIO_PIN_6
#define TC2_cs_GPIO_Port GPIOB
#define TC2_nReady_Pin GPIO_PIN_7
#define TC2_nReady_GPIO_Port GPIOB

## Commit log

2026-01-23 Added BOM
    [LRB_VikramProcter_V1.0.xlsx, LRB_VikramProcter_V2.0.xlsx]
2026-01-23 Added Gerbers
    [PCB2.GBL, PCB2.GBO, PCB2.GBP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]
2026-02-08 BOM stuff for when we were building the board
    [LRB_VikramProcter_BOM_Full.xlsx, LRB_VikramProcter_V2.0.xlsx]
2026-02-21 I have no clue what all these changes are
    [Anemometor_ResDiv1.SchDoc, Anemometor_ResDiv2.SchDoc, LRB_VikramProcter_V1.0.PrjPcb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]
2026-02-21 Added external leds and enclosure links
2026-02-21 Added the stlink connector
2026-04-11 BOM and 3d file again more for assembly
    [LRB_3D.step]
2026-04-12 Updated BOM
    [LRB_VikramProcter_BOM_Full.xlsx]
2026-04-12 Added Encloser 3d print dimensions
2026-05-18 Added image of assebled board to readme
2026-05-18 Moved PCB files to AltiumFiles
    [Anemometor_ResDiv1.SchDoc, Anemometor_ResDiv2.SchDoc, LRB_3D.step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]

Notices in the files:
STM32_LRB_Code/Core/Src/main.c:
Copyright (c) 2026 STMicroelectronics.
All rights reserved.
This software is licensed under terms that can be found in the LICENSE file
